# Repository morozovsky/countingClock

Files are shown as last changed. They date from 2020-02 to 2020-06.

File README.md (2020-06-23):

# countingClock
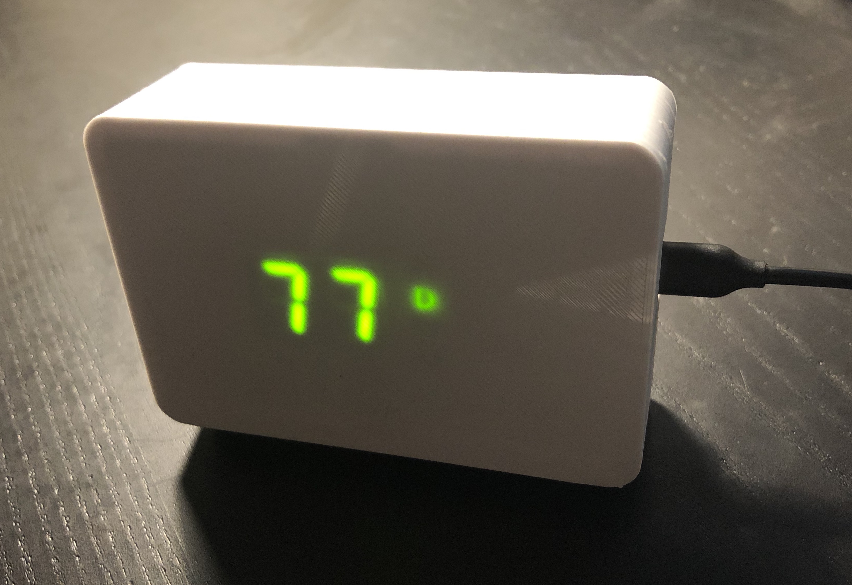
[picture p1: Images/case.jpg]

This repository contains complete code, MCAD, and EECAD for the Counting Clock project. The Counting Clock is an internet-connected thing that displays the amount of time until a specified date and time in the future, or from a specified date and time in the past. The amount of time is displayed in hours, days, weeks, or months, whatever is the smallest unit that fits on a two-digit display (e.g. 48 hours will be displayed instead of 2 days, 52 weeks will be displayed instead of 12 months, etc.). LEDs indicate which unit of time is currently displayed. The internet connection is used only to get the current date and time. No data is uploaded from the device. You specify the date and time (and the WiFi login credentials) by downloading a program from your computer to a microcontroller in the device. You will need a _USB micro B power + data cable_ (not just a charging cable) to program the microcontroller. You can use any powered USB port to power the Counting Clock: wall AC adapter, power bank, computer, or other device.

## Electrical Assembly Instructions
_Almost all of the parts are reverse-polarity sensitive, that is, __if you plug them in backwards, they can be damaged__. It's also important to install parts on the correct side of the board. See the pictures below for reference._

### Required Tools
* Soldering iron (25+ Watts)
* Solder (leaded is easy to work with than lead-free, but don't eat it)
* Snips (to trim excess wire leads)

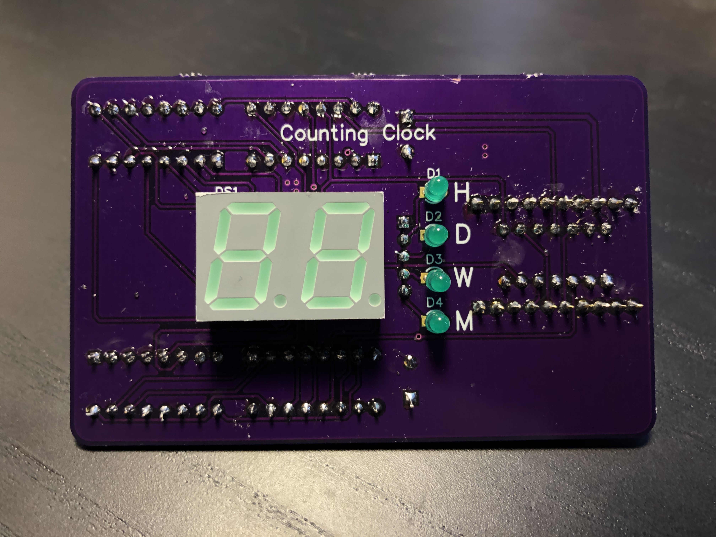
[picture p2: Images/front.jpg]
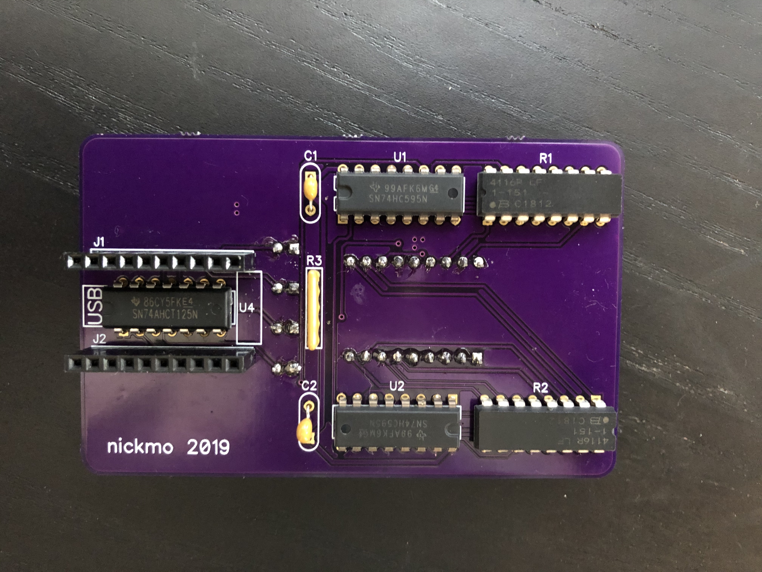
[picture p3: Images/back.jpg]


### Bill of Materials

Quantity | Reference Designator on PCB | Part Description | Manufacturer Part Number | Mouser.com Part Number
------------ | ------------- | ------------- | ------------- | -------------
2 | U1, U2 | Counter Shift Registers DIP 16 pins | SN74HC595N | [595-SN74HC595N](https://www.mouser.com/ProductDetail/595-SN74HC595N)
1 | U4 | Buffers & Line Drivers DIP 14 pins | SN74AHCT125N | [595-SN74AHCT125N](https://www.mouser.com/ProductDetail/595-SN74AHCT125N)
2 | R1, R2 | Resistor Networks DIP 16 pins 150 OHMS Isolated | 4116R-1-151LF | [652-4116R-1LF-150](https://www.mouser.com/ProductDetail/652-4116R-1LF-150)
1 | R3 | Resistor Networks SIP 5 pins 120 OHMS Bussed | 4605X-101-121LF | [652-4605X-1LF-120](https://www.mouser.com/ProductDetail/652-4605X-1LF-120)
2 | C1, C2 | Multilayer Ceramic Capacitors - Leaded 0.1uF 50volts 10% X7R 5mm LS | K104K15X7RF53H5 | [594-K104K15X7RF53H5](https://www.mouser.com/ProductDetail/594-K104K15X7RF53H5)
4 | D1, D2, D3, D4 | Through Hole LED 3mm Green | HLMP-1503-C0002 | [630-HLMP-1503-C0002](https://www.mouser.com/ProductDetail/630-HLMP-1503-C0002)
1 | DS1 | LED Display 2 Digit DIP 18 pins | LTD-5623AG | [859-LTD-5623AG](https://www.mouser.com/ProductDetail/859-LTD-5623AG)
2 | J1, J2 | Female header 10 pins
2 | | Male header 10 pins
1 | | TinyPICO microcontroller

### Assembly
1. Solder the 4 green LEDs. The longer of the two leads goes into the round pad, insert them on the side of the board that has the letters H, D, W, M printed (Counting Clock side). Slide the part as far in as you can, although the green plastic will not be flush with the circuit board. Bend the leads apart so that the LEDs don't slide. After you solder, cut off the excess length of the leads.

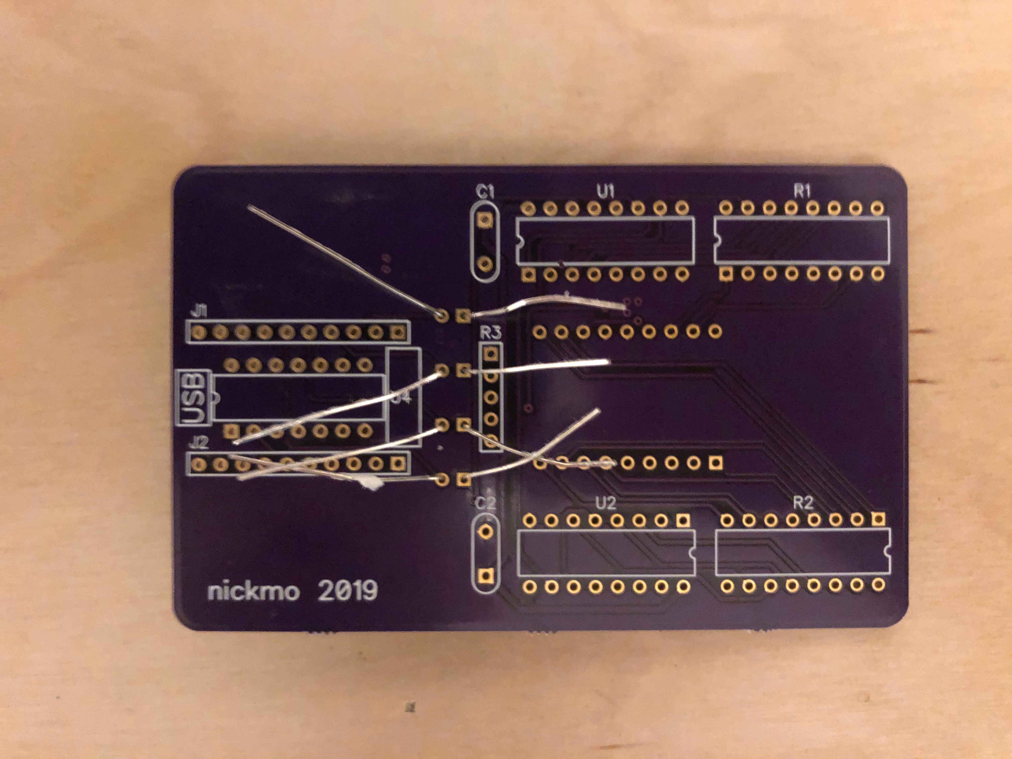
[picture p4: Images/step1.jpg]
    
1. Solder the 5 pin resister network. The dot next to the letter B indicates pin 1 and should go into the square pad on the side of the board that says R3 and has a rectangular outline (nickmo 2019 side).

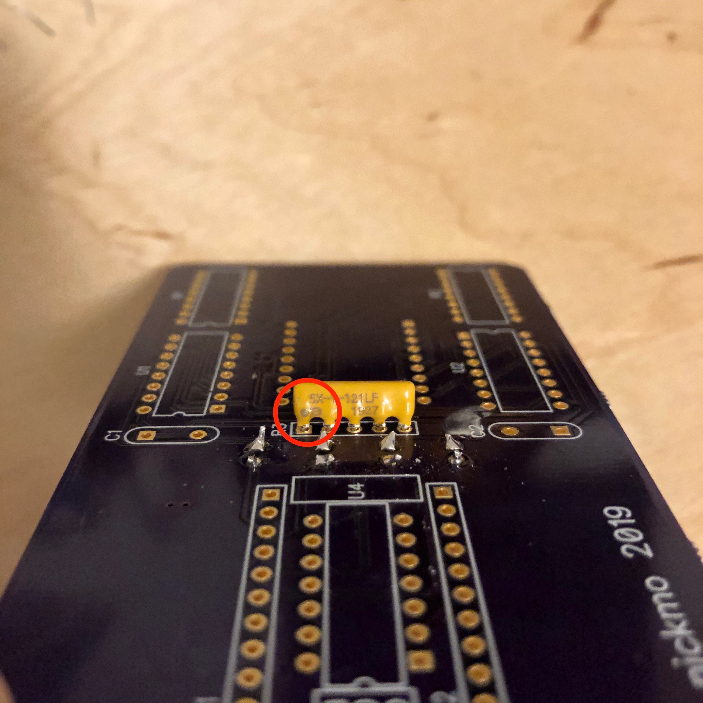
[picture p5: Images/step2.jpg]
    
1. Install the capacitors C1 and C2 on the nickmo 2019 side which has C1 and C2 labeled. For these components, the orientation doesn't matter. Like the LEDs, slide in the components as far as you can and bend the leads to prevent them from sliding out. After you solder, cut off the excess length of the leads.

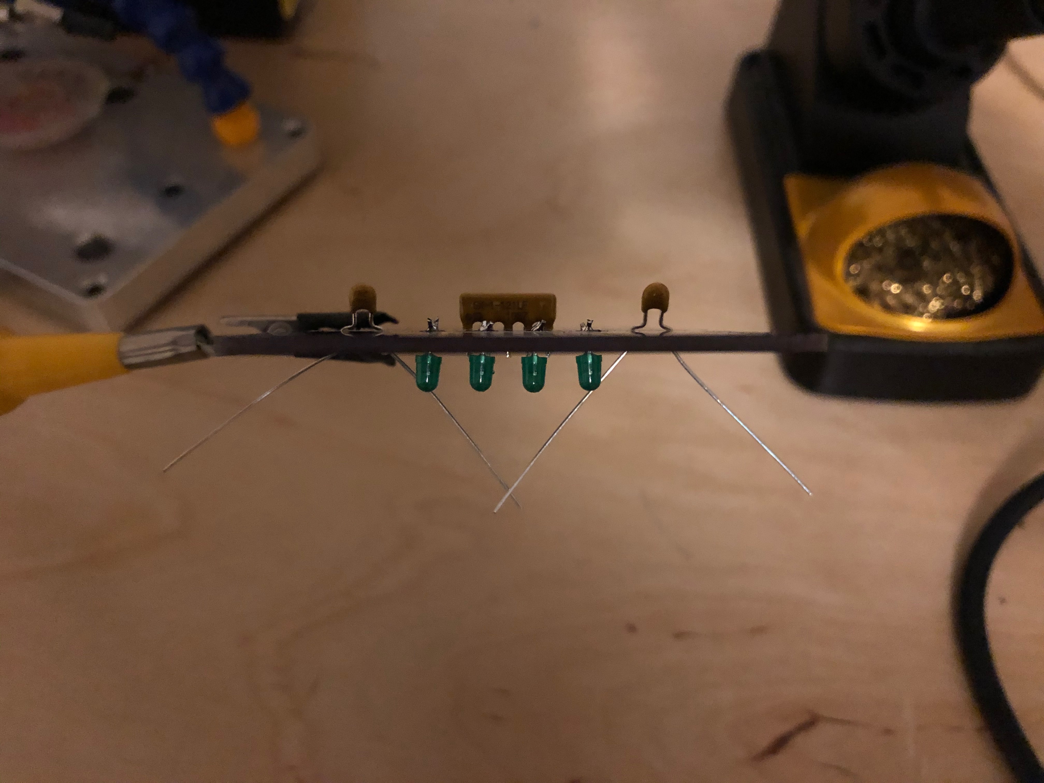
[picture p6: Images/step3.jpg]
    
1. Solder the two two-digit LED display, DS1, on the Counting Clock side of the board. Make sure to line up the decimal places to match the silkscreen printing.

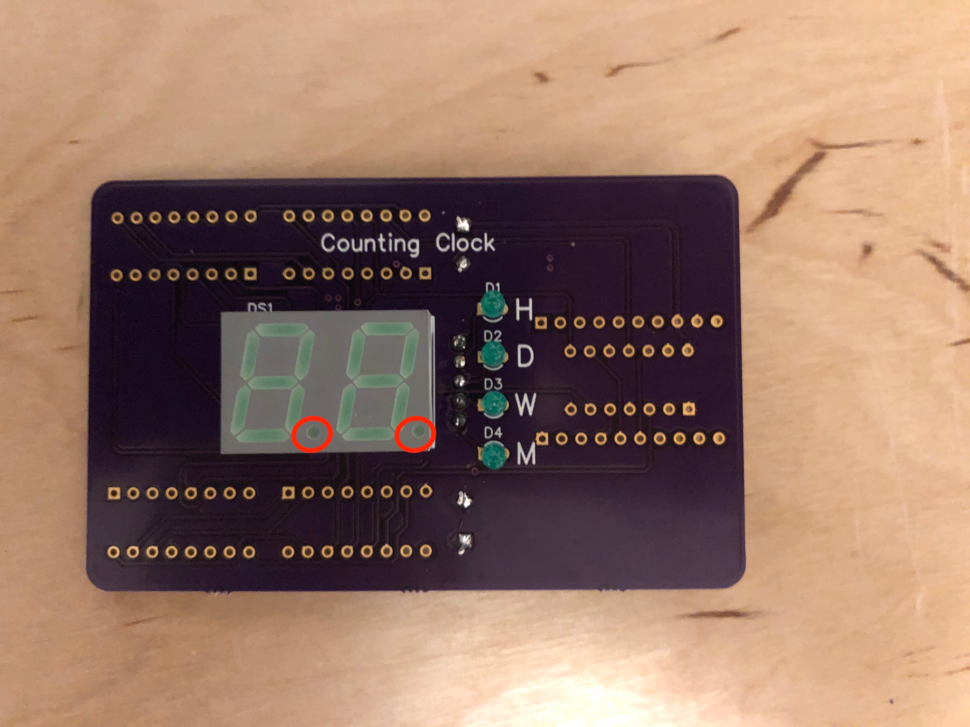
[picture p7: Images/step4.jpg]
    
1. Solder U4, the 14 pin integrated circuit (IC), to the nickmo 2019 side of the board. Make sure to align the U-shaped depression on the IC to the U-shaped mark on the silkscreen printing (next to the USB label). This part is not visible in the picture above because it is below the microcontroller.

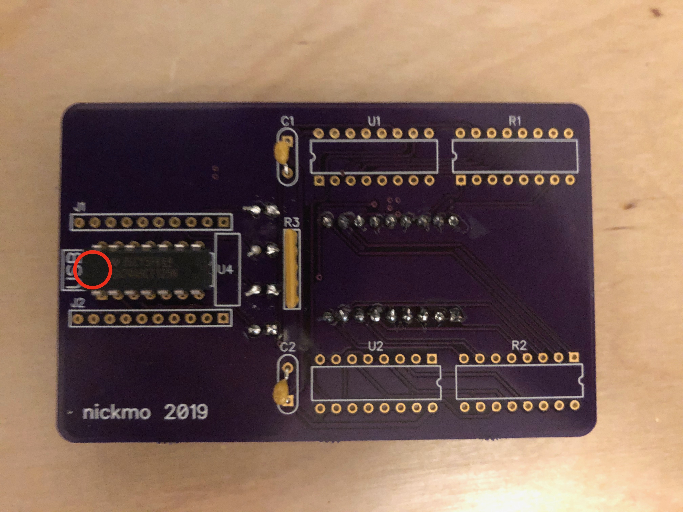
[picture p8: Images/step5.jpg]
    
1. Solder U1 and U2, 16 pin ICs, to the nickmo 2019 side of the board. These parts have the Texas-shaped Texas Instruments logo and the second line of text says "SN74HC595N," they are shorter in height to the other 16 pin ICs (next step). Make sure to align the U-shaped depression on the IC to the U-shaped mark on the silkscreen printing, the two parts have opposite orientations. 

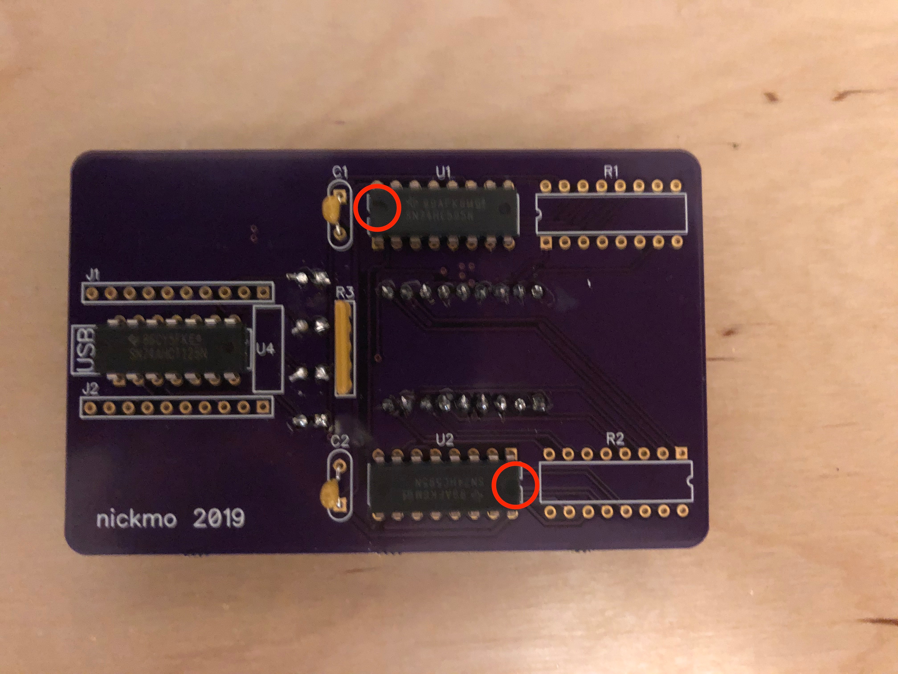
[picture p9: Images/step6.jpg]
    
1. Solder R1 and R2, 16 pin ICs, to the nickmo 2019 side of the board. Make sure to align the U-shaped depression on the IC to the U-shaped mark on the silkscreen printing, the two parts have opposite orientations. 

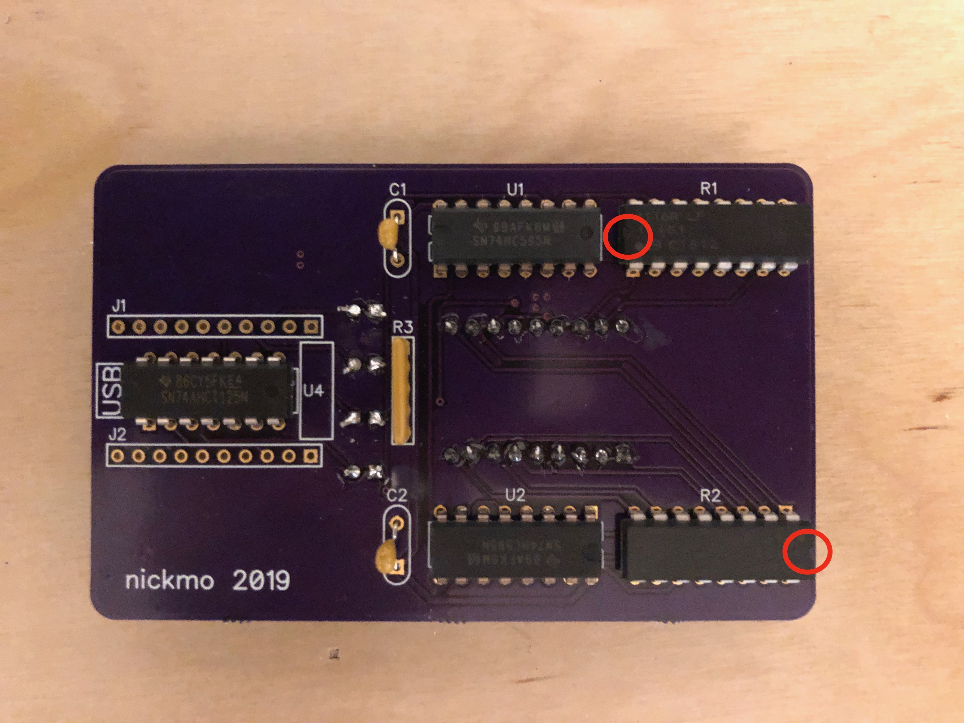
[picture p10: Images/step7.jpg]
    
1. The remaining parts are the 10 pin headers to connect the microcontroller board (with the USB port) to the circuit board. Using male and female headers allows you to remove the microcontroller from the circuit board and use it for other projects too.
    1. The female headers (black enclosure with long gold pins) get soldered to the circuit board and the male headers (gold pins with a thin plastic spacer) get soldered to the microcontroller.
    1. Insert the long side of the male headers into the female headers.

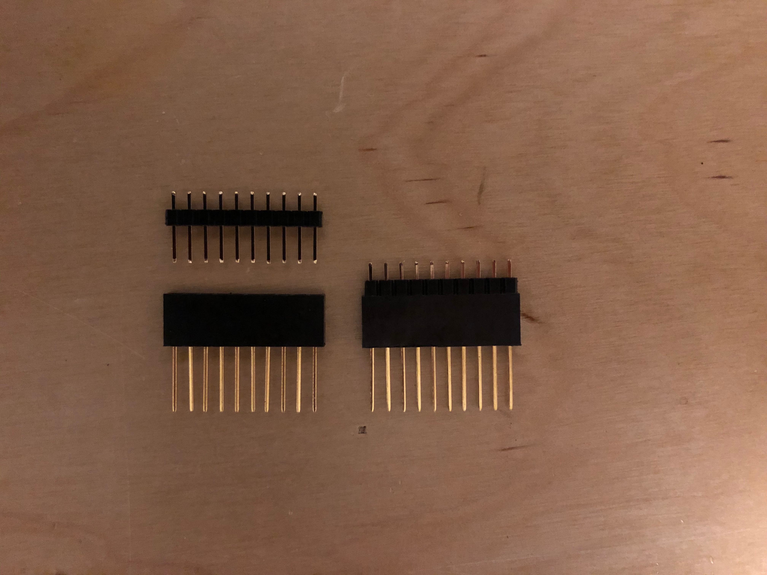
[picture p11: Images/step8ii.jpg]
        
    1. Insert the long pins of the female headers into the circuit board from the nickmo 2019 side, where J1 and J2 are labeled.

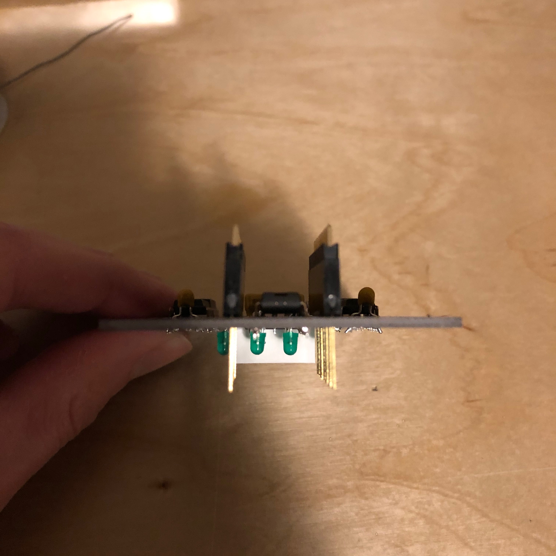
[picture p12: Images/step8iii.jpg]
        
    1. Align the microcontroller onto the short side of the male headers, which should stick up through the microcontroller enough to solder to. Make sure the USB port of the microcontroller is next to the edge of the circuit board, above where "USB" is printed on silkscreen on the circuit board.

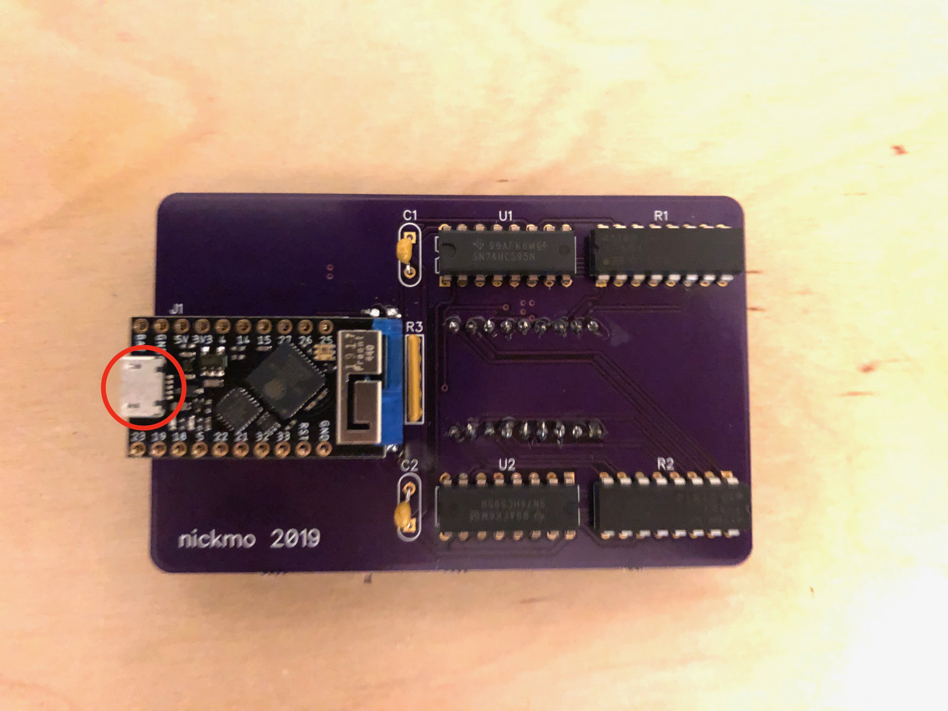
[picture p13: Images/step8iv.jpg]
        
    1. Solder the male header pins (2 x 10 pins) to the microcontroller while making sure that the headers are perpendicular to both the microcontroller and the circuit board. I recommend doing the corner pins first to lock in the alignment.
    1. Solder the female header pins (2 x 10 pins) to the circuit board. Trim the excess length once you're done.
1. With a USB micro cable, plug the microcontroller into a powered USB port. You should see a few LEDs light up on the microcontroller (but not the ones on the circuit board, yet). If you see any magic smoke escape, reconsider the decisions you've made up to this point.
_There's a couple extra connectors in the bag, they are not needed. Do not eat them or the silica gel._

## Mechanical Assembly Instructions
1. Push the tabs in the case towards the edges of the case and slide in the circuit board, make sure to align the LED display and LEDs towards the openings (it will only fit one way).

## Software Instructions
1. Download and install the USB to UART drivers for your computer from: https://www.silabs.com/products/development-tools/software/usb-to-uart-bridge-vcp-drivers
1. Download and install the Arduino IDE from: https://www.arduino.cc/en/main/software
1. Inside the Arduino IDE, select Preferences
    1. In the Settings tab, in the "Additional Boards Manager URLs" text box, add this URL: https://raw.githubusercontent.com/espressif/arduino-esp32/gh-pages/package_esp32_index.json
1. Inside the Arduino IDE, select Tools -> Board -> Boards Manager
    1. Search for (text box in the upper right hand corner of the Boards Manager window) and install the esp32 package
1. Inside the Arduino IDE, select Sketch -> Include Library -> Manage Libraries...
    1. Search for (text box in the upper right hand corner of the Library Manager window) and install the TinyPICO Helper Library
    1. Search for and install the Time library by Michael Margolis (make sure to install this library, not any other version)
1. Download the code from this GitHub repository to your computer. The simplest option is to right click on these links and save them to your computer in a dedicated folder: [constants.h](https://raw.githubusercontent.com/morozovsky/countingClock/master/Software/counting_clock/constants.h) [counting_clock.ino](https://raw.githubusercontent.com/morozovsky/countingClock/master/Software/counting_clock/counting_clock.ino) For extra credit, clone this repository to your computer.
1. Open counting_click.ino in Arduino IDE and it will also open constants.h in another tab. Modify the values in constants.h to set the second, minute, hour, day, month, and year you want to count down to (or up from) and your WiFi network name (SSID) and password, both are case-sensitive. Save your changes.
1. Connect your computer to the microcontroller with a USB micro B cable.
1. From the Tools -> Board menu, select TinyPICO.
1. Upload the program to the microcontroller. This will take some time as the code is compiled and transferred to the microcontroller.
1. You can open the Serial Monitor (magnifying glass option in the top right corner of the Arduino window) to see updates from the microcontroller. You can use this to test the microcontroller by itself or assembled to the circuit board.

## Next Steps
Want to take things a step further? Here's a few ideas:
* Modify the code to use different time steps, e.g. {seconds, minutes, hours, days}
* Rewrite the code to turn it into weather display that shows the temperature and indicates {sunny, partly cloudy, cloudy, rain}
* Design and 3D print a back cover

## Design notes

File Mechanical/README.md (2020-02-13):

The case design was created with Onshape https://www.onshape.com a 'CAD in the cloud' platform with a free plan for hobbyists (pay-for-privacy mdoel).
This directory contains an .STL file of the case design suitable for 3D printing (print without supports with the front face of the case on the printing platform) and the .gcode file for an Ultimaker 2+
You can access the original design at this link:
https://cad.onshape.com/documents/9f0145f998cc6048aedce769/w/c83123141f25a2bc8a938d93/e/fff58c679c832438525f7a51

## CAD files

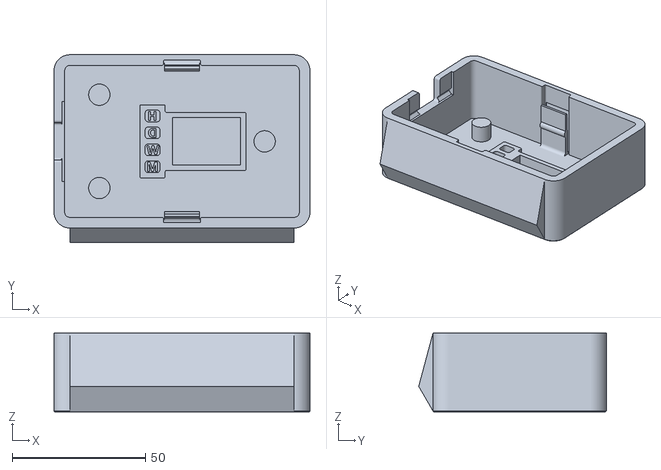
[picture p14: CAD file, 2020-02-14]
Mechanical/counting_clock - case.stl
96.0 x 70.3 x 29.5

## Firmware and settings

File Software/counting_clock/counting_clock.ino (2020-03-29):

#include <TinyPICO.h>
#include <WiFi.h>
#include <TimeLib.h>
#include "constants.h"

tmElements_t target_time = {target_second, target_minute, target_hour-gmt_offset_hours, 0, target_day, target_month, CalendarYrToTm(target_year) };
time_t target_epoch_time = makeTime(target_time);
time_t time_now;
int delta_time_hours;
byte MSB;
byte LSB;

TinyPICO tp = TinyPICO();

#define hoursLED              (27)
#define daysLED               (15)
#define weeksLED              (14)
#define monthsLED             (4)
#define data_pin              (22)
#define clock_pin             (33)
#define latch_pin             (32)
#define not_output_enable_pin (21)

const char* ntpServer = "pool.ntp.org";
const long  gmtOffset_sec = gmt_offset_hours*60*60;
const int   daylightOffset_sec = use_daylight_savings * 3600;

enum time_units
{
  hours,
  days,
  weeks,
  months,
  all
};

void set_time_units(int units)
{
  switch(units)
  {
    case hours:
      digitalWrite(hoursLED, HIGH);
      digitalWrite(daysLED, LOW);
      digitalWrite(weeksLED, LOW);
      digitalWrite(monthsLED, LOW);
      Serial.println(" hours");
      break;
    case days:
      digitalWrite(hoursLED, LOW);
      digitalWrite(daysLED, HIGH);
      digitalWrite(weeksLED, LOW);
      digitalWrite(monthsLED, LOW);
      Serial.println(" days");
      break;
    case weeks:
      digitalWrite(hoursLED, LOW);
      digitalWrite(daysLED, LOW);
      digitalWrite(weeksLED, HIGH);
      digitalWrite(monthsLED, LOW);
      Serial.println(" weeks");
      break;
    case months:
      digitalWrite(hoursLED, LOW);
      digitalWrite(daysLED, LOW);
      digitalWrite(weeksLED, LOW);
      digitalWrite(monthsLED, HIGH);
      Serial.println(" months");
      break;
    case all:
      digitalWrite(hoursLED, HIGH);
      digitalWrite(daysLED, HIGH);
      digitalWrite(weeksLED, HIGH);
      digitalWrite(monthsLED, HIGH);
      Serial.println(" overflow");
      break;
  }
}

void display_reset()
{
  digitalWrite(not_output_enable_pin, HIGH);
  digitalWrite(latch_pin, LOW);
  shiftOut(data_pin, clock_pin, LSBFIRST, 0);
  shiftOut(data_pin, clock_pin, LSBFIRST, 0);
  digitalWrite(latch_pin, HIGH);
  digitalWrite(not_output_enable_pin, LOW);
}

void display_FI()
{
  digitalWrite(latch_pin, LOW);
  shiftOut(data_pin, clock_pin, LSBFIRST, B01100000);
  shiftOut(data_pin, clock_pin, LSBFIRST, B10001110);
  digitalWrite(latch_pin, HIGH);
}

void display_number(int digits)
{
  Serial.print(digits);
  if (digits > 9)
  {
    MSB = digit_to_byte(digits / 10);
    LSB = digit_to_byte(digits % 10);
  }
  else
  {
    MSB = digit_to_byte(-1);
    LSB = digit_to_byte(digits);
  }
  // shift out to seven segment displays
  digitalWrite(latch_pin, LOW);
  shiftOut(data_pin, clock_pin, LSBFIRST, LSB);
  shiftOut(data_pin, clock_pin, LSBFIRST, MSB);
  digitalWrite(latch_pin, HIGH);
}

byte digit_to_byte(int digit)
{
  switch(digit)
  {
    case -1:
      return B00000000;
      break;
    case 0:
      return B11111100;
      break;
    case 1:
      return B01100000;
      break;
    case 2:
      return B11011010;
      break;
    case 3:
      return B11110010;
      break;
    case 4:
      return B01100110;
      break;
    case 5:
      return B10110110;
      break;
    case 6:
      return B10111110;
      break;
    case 7:
      return B11100000;
      break;
    case 8:
      return B11111110;
      break;
    case 9:
      return B11110110;
      break;
    default:
      return B00011110;
      break; 
  }
}

void setup()
{
  pinMode(hoursLED, OUTPUT);
  pinMode(daysLED, OUTPUT);
  pinMode(weeksLED, OUTPUT);
  pinMode(monthsLED, OUTPUT);
  pinMode(data_pin, OUTPUT);
  pinMode(clock_pin, OUTPUT);
  pinMode(latch_pin, OUTPUT);
  pinMode(not_output_enable_pin, OUTPUT);

  display_reset();
  
  Serial.begin(115200);
  Serial.print("Target epoch time: ");
  Serial.println(target_epoch_time);
  
  WiFi.disconnect(true);
  WiFi.mode(WIFI_OFF);
  WiFi.begin(secret_ssid, secret_password);
  delay(100);
  display_FI();
  while (WiFi.status() != WL_CONNECTED)
  {
    Serial.print("Trying to connect to SSID: ");
    Serial.print(secret_ssid);
    Serial.print(" with password: ");
    Serial.println(secret_password);
    delay(500);
    digitalWrite(not_output_enable_pin, !digitalRead(not_output_enable_pin));
  }
  display_reset();
  configTime(gmtOffset_sec, daylightOffset_sec, ntpServer);
  time(&time_now);
  delay(1000);
}

void loop()
{
  time(&time_now);
  Serial.print("Delta seconds: ");
  Serial.println(target_epoch_time - time_now);
  delta_time_hours = abs(target_epoch_time - time_now) / 3600;
  if (delta_time_hours < 1)
  {
    display_number(0);
    set_time_units(hours);
  }
  else if (delta_time_hours < 100)
  {
    display_number(delta_time_hours);
    set_time_units(hours);
  }
  else if (delta_time_hours < 100*24)
  {
    display_number(delta_time_hours/24);
    set_time_units(days);
  }
  else if (delta_time_hours < 100*24*7)
  {
    display_number(delta_time_hours/24/7);
    set_time_units(weeks);
  }
  else if (delta_time_hours < 100*24*(365.24/12))
  {
    display_number(delta_time_hours/24/(365.24/12));
    set_time_units(months);
  }
  else
  {
    display_number(99);
    set_time_units(all);
    delay(10000); // delay 10 seconds
    return;
  }

  delay(120000); // update every 2 minutes

}

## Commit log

2020-02-13 add Ultimaker 2+ gcode for case
2020-02-14 STL of case
    [counting_clock - case.stl]
2020-02-15 add PCB design files, libraries, and gerbers
    [BoardOutline.gbr, Bottom.gbr, BottomAssy.gbr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]
2020-02-17 add Arduino tinypico sketch
2020-02-29 add picture in case
2020-03-03 electrical assembly photos
2020-03-03 Update README.md
    Add photos to electrical assembly instructions
2020-06-23 Update README.md
    Add instructions to add additional boards manager URL for esp32 json file
2020-06-23 Update README.md
    Add link for downloading USB-to-UART drivers
